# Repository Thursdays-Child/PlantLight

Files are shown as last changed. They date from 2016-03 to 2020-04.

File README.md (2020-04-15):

# PLANT LIGHT 
### Automatic light switch based on light sensor and date/time

**version 3.0**
Replaced transistor with phototransistor to switch the relay. 

**version 2.0**
Upgraded PCB and logic with ATMega328p and Maxim DS3231M RTC. New schematich and new PCB. The temperature compensated clock
now wakes up the micro once per day, with time of day alarm.

**version 1.2**
Added function to set time from an external input, with all the istructions needed: set draft info on RTC clock.
Linked against new ATTiny CORE library, that has changed the RX and TX pin for serial debug.

**version 1.1**

Added TimeZone library to account for DST (summer time). The TimeZone has been added to the DS1307RTC library,
and slightly modified to remove ARDUINO define, not present in my development environment. 
The timezone rules are saved into an EEPROM image (to save program memory on the small ATTiny85): the image is in 
Intel HEX format.

Library reference at https://github.com/JChristensen/Timezone

**version 1.0**

The project is an automatic switch for 2 LED lamps used to illuminate 
some plants in my house. On board there is a real time clock, to keep track of 
the actual date and time even on power loss, and the light sensor is placed 
on a separate breakout board. A relay switches the main power (230 V AC) to 
the LEDs. The micro is an Atmel ATTiny 85V.

The project is compiled for Atmel AVR, with standard AVR GCC toolchain. 
Eclipse was used to create and compile the projects, with the AVR Plugin.

A makefile is available to compile without Eclispe. 

This project consists of a main C++ file and some libraries (C/C++):

* BH1750FVI: control the light sensor (BH1750) to read the lux value and 
  put to sleep/wake up the sensor;
* DS1307: real time clock library, to read the actual date and time.
* TinyWireM: Wire library modified to work on small ATTiny, were the I2C management 
  hardware is not present. The library uses the internal USI hardware to communicate 
  over serial connection, and implement I2C protocol (reference http://playground.arduino.cc/Code/USIi2c).
* TinySerialDebug: library to use serial communication only for debug purpose 
  on the ATTiny. The configuration allows only 3 fixed speeds (baud/s) and the 
  communication is transmission only from the micro (reference https://code.google.com/archive/p/arduino-tiny/).

The sensors library have been modified to work with the same instance of the 
I2C bus control class, and each functionality has been tested with the hardware. 
The documentation folder contains:

* the bill of material;
* datasheet of used components;
* electrical drawings;

Some pictures can be found at https://goo.gl/photos/P42G4u1Tg8iYygQf6

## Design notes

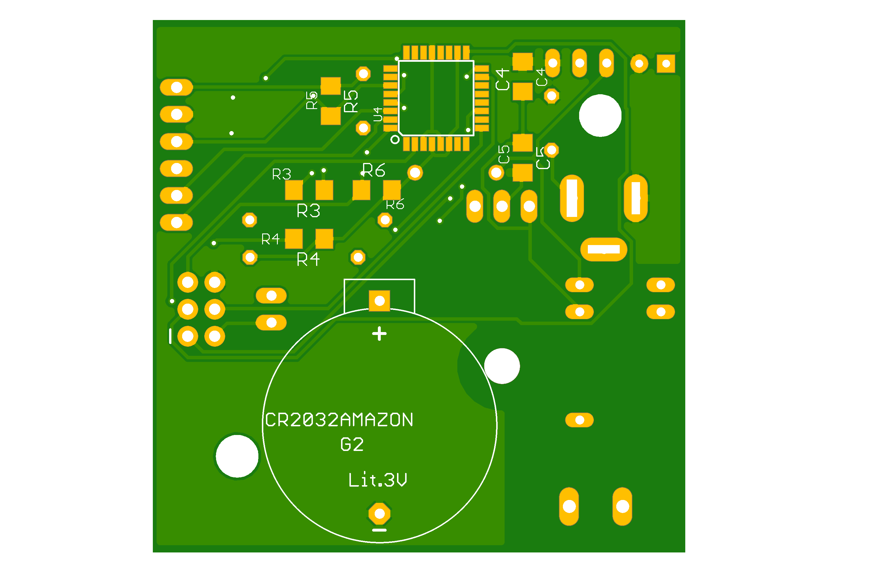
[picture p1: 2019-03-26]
Documentation/Schematics/PlantLight/Main_board_bottom.png

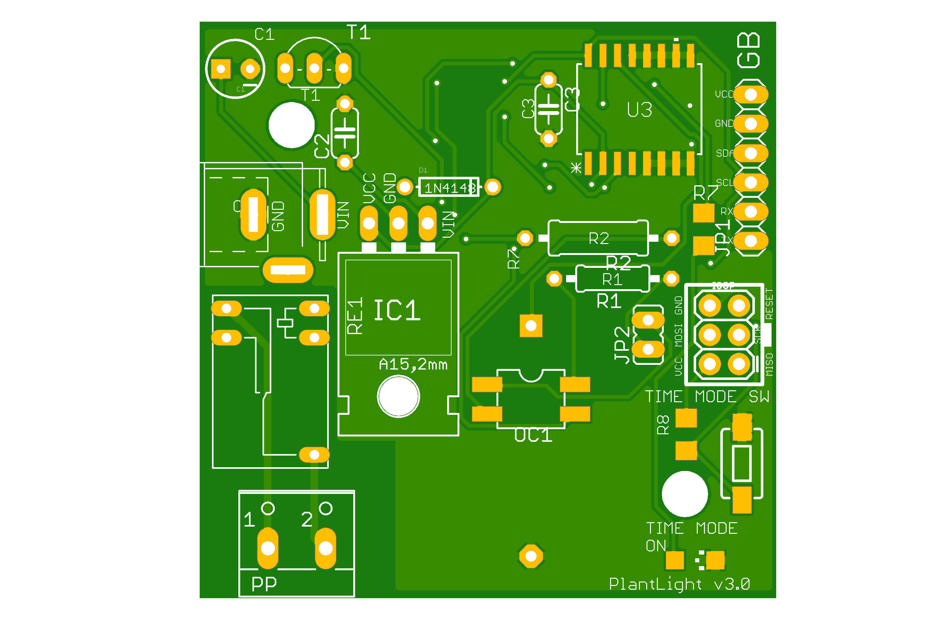
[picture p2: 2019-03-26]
Documentation/Schematics/PlantLight/Main_board_top.png

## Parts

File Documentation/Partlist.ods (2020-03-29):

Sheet: Order
PLANT LIGHT BOARD – TOTAL COST OF ORDER |  |  |  |  |  |  |  | (with tools etc..)
Part | Value | Device | Package | X | Where | Quantity | Price
C1 | 0.33uF | C-US025-024X044 | C025-024X044 |  | EbmStore | 10 | € 0,80
C2 | 100uF | CAP_POLPTH2 | CPOL-RADIAL-10UF-25V | X
C3 | 0.1uF | C-US025-024X044 | C025-024X044 | X
D1 | 1N4148 | DIODE1N4148 | DIODE-1N4148 | X
G1 | CR2032H | CR2032H | CR2032H |  | EbmStore | 1 | € 0,90
IC1 | 5V | 78XXL | 78XXL |  | EbmStore | 2 | € 0,80
IC2 | DS1307 | DS1307 | DIL08 |  | EbmStore | 1 | € 0,90
Q2 | 32768 | CRYTALTC38H | TC38H
JP1 |  | PINHD-1X6 | 1X06 |  | EbmStore | 5 | € 0,90
JP2 |  | PINHD-1X6 | 1X06
PP | 0 | W237-102 | W237-102 | X
Q1 | 2N3904 | TRANSISTOR_NPNTO92 | TO-92 | X
R1 | 1K | R-US_0207/10 | 0207/10 | X
R2 | 10K | R-US_0309/12 | 0309/12 | X
R3 | 10K | R-US_0309/12 | 0309/12 | X
R4 | 4K7 | R-US_0207/10 | 0207/10 |  | EbmStore | 10x2 | € 0,48
R5 | 4K7 | R-US_0207/10 | 0207/10
R6 | 4K7 | R-US_0207/10 | 0207/10
RE1 | R414D | R414D | R414D |  | EbmStore | 2 | € 1,60
U1 | TINY85-20-DIP | ATTINY45TINY85-20-DIP | DIP08 |  | EbmStore | 1 | € 1,80
X1 |  | MPT2 | 2POL254 |  | EbmStore | 2 | € 1,20
 |  | Micro SD reader |  |  | EbmStore | 1 | € 2,80
 |  | ABS box 90x56x23 |  |  | EbmStore | 1 | € 1,20
 |  | 8-DIP socket |  |  | EbmStore | 10 | € 1,00
 |  | RS232 to TTL converter |  |  | EbmStore | 1 | € 3,50
 |  | Flat cable 4 poles 1m |  |  | Ebay | 1 | € 2,70
 |  | BH1750FVI Digital Light Intensity Sensor Module |  |  | Ebay | 1 | € 1,32
 |  | CR2032 coin battery Duracell |  |  | Ebay | 2 | € 2,00
 |  |  |  |  | Paypal tax | Shipment | TOTAL
 |  |  |  |  | € 0,41 | € 8,28 | € 32,59

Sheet: BOM_v1.1
PROJECT BOM
Component | Quantity | Price | Total Cost | Shipment Cost
Electronic
Flat cable 4 poles 1m | 1 | € 2,70 | € 2,70
BH1750FVI Digital Light Intensity Sensor Module | 1 | € 1,32 | € 1,32
CR2032 coin battery Duracell | 2 | € 1,00 | € 2,00 | € 1,78
Capacitor 0.33uF, 100uF, 0.1uF | 3 | € 0,08 | € 0,24 | € 6,50 | EbmStore
Diode 1N4148 | 1 | € 0,00 | € 0,00
Coin battery holder CR2032H | 1 | € 0,90 | € 0,90
5V positive regulator 78XXL | 1 | € 0,80 | € 0,80
RTC DS1307 | 1 | € 0,90 | € 0,90
Pin Header X5 | 2 | € 0,18 | € 0,36
Screw contact W237-102 | 1 | € 0,00 | € 0,00
Transistor 2N3904 | 1 | € 0,00 | € 0,00
Oscillator 32KHz | 1 | € 0,00 | € 0,00
Resistors 1K, 10K, 4K7 | 6 | € 0,02 | € 0,12
Relay 5Vdc – 3A | 1 | € 0,80 | € 0,80
ATTiny85-U | 1 | € 0,00 | € 0,00
Screw contact 2.54mm | 1 | € 0,60 | € 0,60
8-DIP socket | 2 | € 0,10 | € 0,20
BH1750FVI Digital Light Intensity Sensor Module | 1 | € 1,20 | € 1,20
Construction
Flat cable 4 poles 1m | 1 | € 1,30 | € 1,30
ABS box 55x57x28 | 1 | € 1,20 | € 1,20
Bipolar cable | 1 | € 0,50 | € 0,50
220V Socket | 1 | € 2,60 | € 2,60
Sensor holder | 1 | € 1,00 | € 1,00
 |  |  | € 18,74 | € 8,28
 |  |  |  | TOTAL
 |  |  |  | € 27,02

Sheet: BOM_v2.0
X | Part | Value | Device | Package | Library
x | C1 | 100uF | CAP_POLPTH2 | CPOL-RADIAL-10UF-25V | Capacitor Polarized
x | C2 | 0.33uF | C-US050-024X044 | C050-024X044 | CAPACITOR, American symbol
x | C3 | 0.1uF | C-US050-024X044 | C050-024X044 | CAPACITOR, American symbol
x | C4 | 0.1uF | C-EUC1206 | C1206 | CAPACITOR, European symbol
x | C5 | 0.1uF | C-EUC1206 | C1206 | CAPACITOR, European symbol
x | D1 | 1N4148 | DIODE1N4148 | DIODE-1N4148 | Diode
x | G2 | CR2032AMAZON | CR2032AMAZON | CR2032_AMAZON | Battery holder CR2032 from:
x | IC1 | 5V | 78XXL | 78XXL | VOLTAGE REGULATOR
x | ICSP | AVR_SPI_PROG | AVR_SPI_PROG_3X2PTH | 2X3 | AVR ISP 6 Pin
x | JP1 |  | PINHD-1X6 | 1X06 | PIN HEADER
x | PP |  | W237-102 | W237-102 | WAGO SCREW CLAMP
x | R1 | 1K | R-US_0207/10 | 0207/10 | RESISTOR, American symbol
x | R2 | 10K | R-US_0309/12 | 0309/12 | RESISTOR, American symbol
x | R3 | 18K | R-US_R1206 | R1206 | RESISTOR, American symbol
x | R4 | 18K | R-US_R1206 | R1206 | RESISTOR, American symbol
x | R5 | 18K | R-US_R1206 | R1206 | RESISTOR, American symbol
x | R6 | 18K | R-US_R1206 | R1206 | RESISTOR, American symbol
x | R7 | 560 | R-US_R1206 | R1206 | RESISTOR, American symbol
x | R8 | 18K | R-US_R1206 | R1206 | RESISTOR, American symbol
x | RE1 | SRSZ-SL5VDC | SRSZ-SL5VDC | SRSZ-SL | SRSZ-05VDC-SL Relay from EbmStore
x | T1 | 2N3904 | 2N3904-NPN-TO92-EBC | TO92-EBC | NPN Transistror
x | TIME_MODE | YELLOW | LEDCHIPLED_1206 | CHIPLED_1206 | LED
x | TIME_MODE_SW | SPST-SMD | MOMENTARY-SWITCH-SPST-SMD-6.0X3.5MM | TACTILE_SWITCH_SMD_6.0X3.5MM | Momentary Switch (Pushbutton) - SPST
x | U3 | DS3231M+TRL | DS3231M+TRL | 21-0042B_16
x | U4 | ATMEGA8/168/328 | ATMEGA8/168/328 | TQFP32 | MICROCONTROLLER
x | X1 |  | MPT2 | 2POL254 | PHOENIX CONNECTOR

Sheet: BOM_v3.0
X | Part | Value | Device | Package | Description
x | C1 | 100uF | CAP_POLPTH2 | CPOL-RADIAL-10UF-25V | Capacitor Polarized
x | C2 | 0.33uF | C-US050-024X044 | C050-024X044 | CAPACITOR, American symbol
x | C3 | 0.1uF | C-US050-024X044 | C050-024X044 | CAPACITOR, American symbol
x | C4 | 0.1uF | C-EUC1206 | C1206 | CAPACITOR, European symbol
x | C5 | 0.1uF | C-EUC1206 | C1206 | CAPACITOR, European symbol
x | D1 | 1N4148 | DIODE1N4148 | DIODE-1N4148 | Diode
x | G2 | CR2032AMAZON | CR2032AMAZON | CR2032_AMAZON | Battery holder CR2032 from:
x | IC1 | 5V | 78XXL | 78XXL | VOLTAGE REGULATOR
x | ICSP | AVR_SPI_PROG | AVR_SPI_PROG_3X2PTH | 2X3 | AVR ISP 6 Pin
x | J1 |  | JACK-PLUG0 | SPC4077 | DC POWER JACK
x | JP1 |  | PINHD-1X6 | 1X06 | PIN HEADER
x | JP2 |  | JP1E | JP1 | JUMPER
x | OC1 |  | PC817SMD | SMD04 | SHARP OPTO COUPLER
 | PP | 0 | W237-102 | W237-102 | WAGO SCREW CLAMP
x | R1 | 1K | R-US_0207/10 | 0207/10 | RESISTOR, American symbol
x | R2 | 560 | R-US_0309/12 | 0309/12 | RESISTOR, American symbol
x | R3 | 18K | R-US_R1206 | R1206 | RESISTOR, American symbol
x | R4 | 18K | R-US_R1206 | R1206 | RESISTOR, American symbol
x | R5 | 18K | R-US_R1206 | R1206 | RESISTOR, American symbol
x | R6 | 18K | R-US_R1206 | R1206 | RESISTOR, American symbol
x | R7 | 560 | R-US_R1206 | R1206 | RESISTOR, American symbol
x | R8 | 18K | R-US_R1206 | R1206 | RESISTOR, American symbol
x | RE1 | SRSZ-SL5VDC | SRSZ-SL5VDC | SRSZ-SL | SRSZ-05VDC-SL Relay from EbmS
x | T1 |  | 2N5551-NPN-TO92-CBE | TO92-CBE | NPN Transistror
x | TIME_MODE | YELLOW | LEDCHIPLED_1206 | CHIPLED_1206 | LED
x | TIME_MODE_SW | SPST-SMD | MOMENTARY-SWITCH-SPST-SMD-6.0X3.5MM | TACTILE_SWITCH_SMD_6.0X3.5MM | Momentary Switch (Pushbutton)
x | U3 | DS3231M+TRL | DS3231M+TRL | 21-0042B_16 | Real Time Clock
x | U4 | ATMEGA8/168/328 | ATMEGA8/168/328 | TQFP32 | MICROCONTROLLER

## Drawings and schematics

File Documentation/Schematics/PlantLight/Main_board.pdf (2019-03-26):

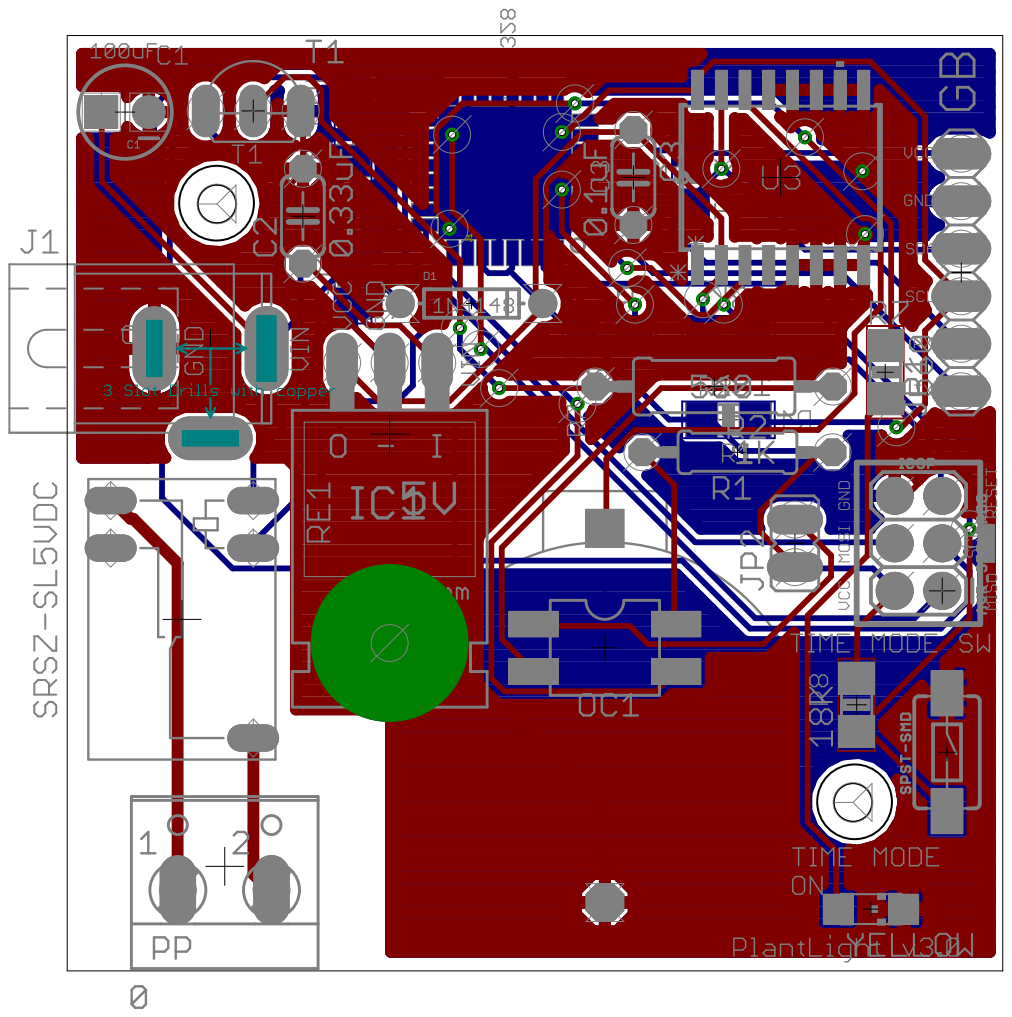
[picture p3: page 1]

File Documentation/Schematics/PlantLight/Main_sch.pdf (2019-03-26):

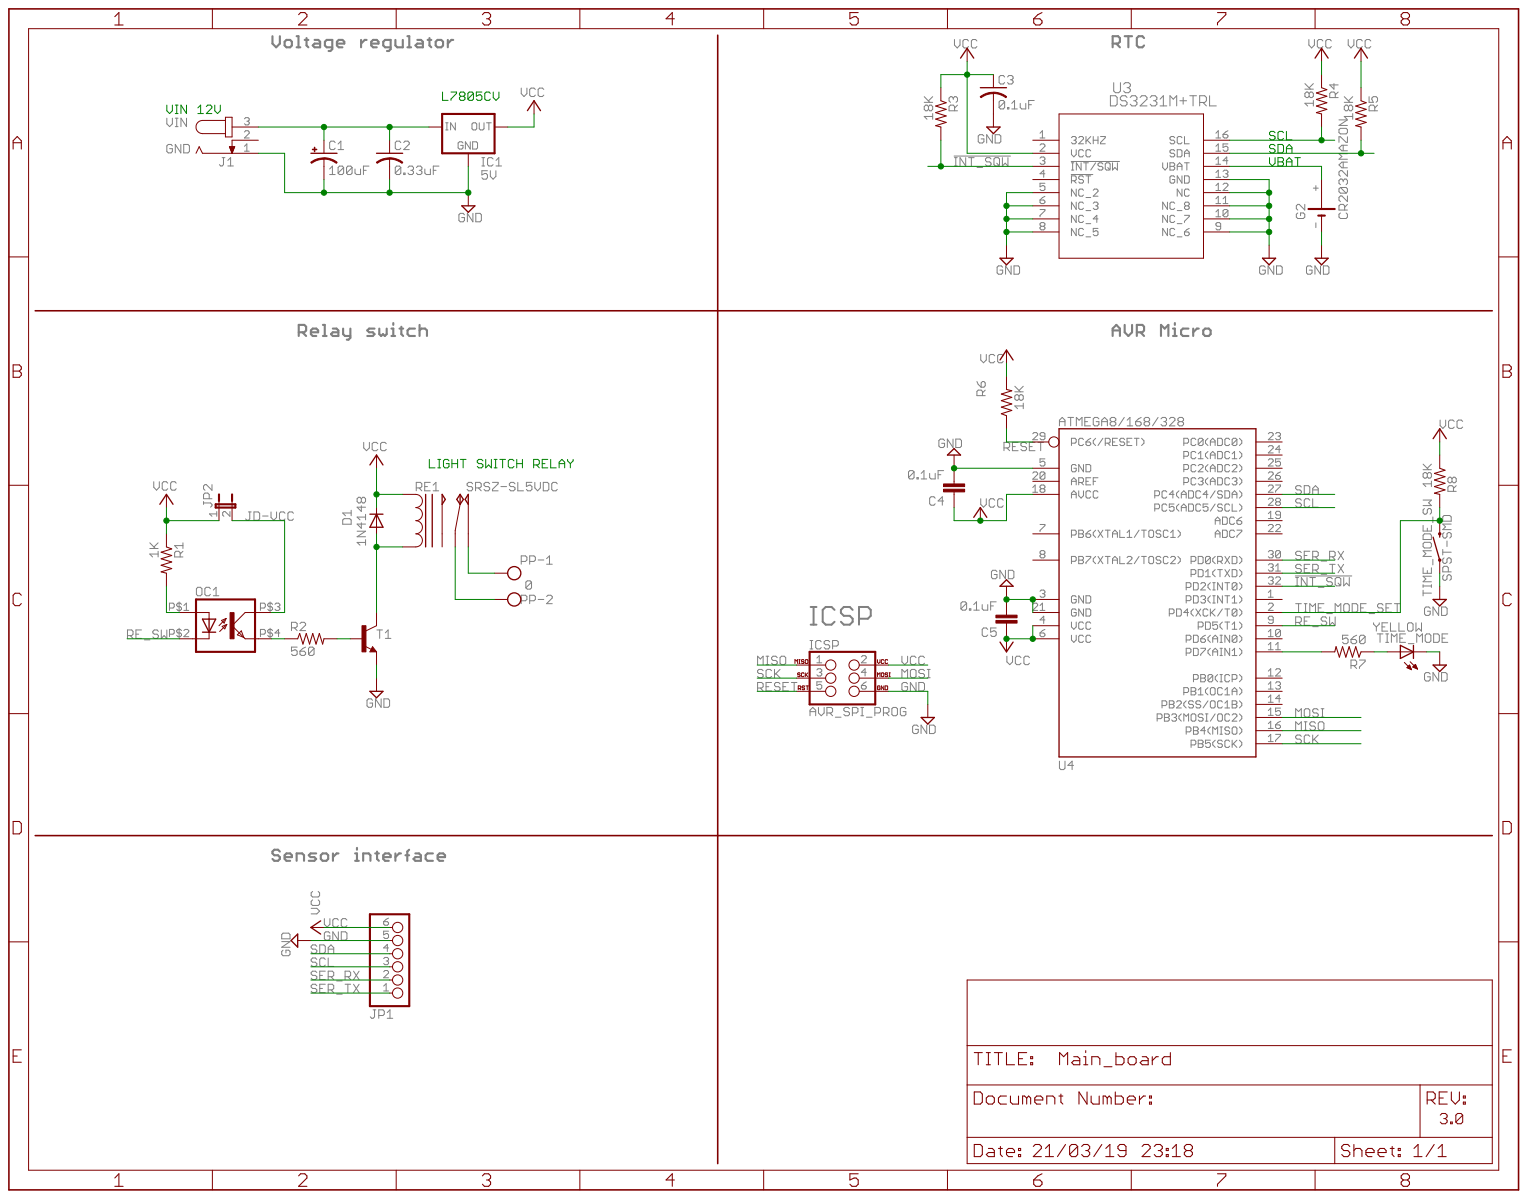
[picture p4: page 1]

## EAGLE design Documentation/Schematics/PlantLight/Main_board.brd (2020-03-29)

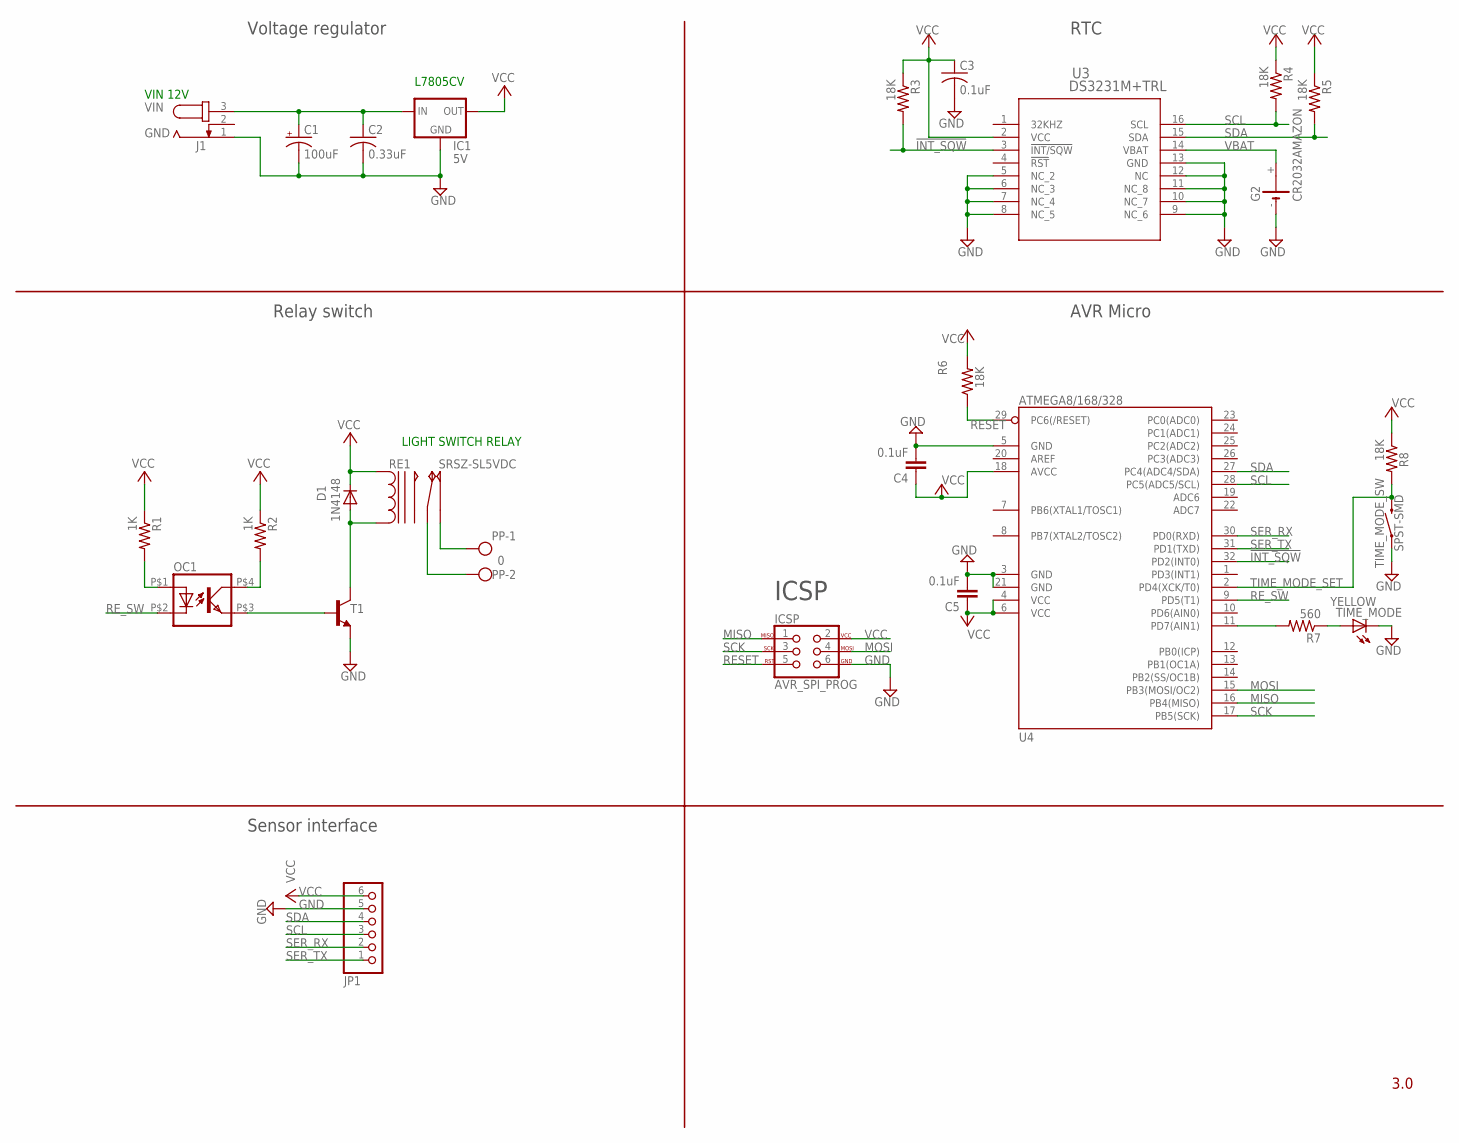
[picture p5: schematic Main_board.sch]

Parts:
C1: 100uF; CPOL-RADIAL-10UF-25V
C2: 0.33uF; C050-024X044
C3: 0.1uF; C050-024X044
C4, C5: 0.1uF; C1206
D1: 1N4148; DIODE-1N4148
G2: CR2032AMAZON; CR2032_AMAZON
IC1: 5V; 78XXL
ICSP: AVR_SPI_PROG; 2X3
J1: JACK-PLUG0; SPC4077
JP1: PINHD-1X6; 1X06
OC1: PC817SMD; SMD04
PP: 0; W237-102
R1, R2: 1K; 0207/10
R3, R4, R5, R6, R8: 18K; R1206
R7: 560; R1206
RE1: SRSZ-SL5VDC; SRSZ-SL
T1: 2N5551-NPN-TO92-CBE; TO92-CBE
TIME_MODE: YELLOW; CHIPLED_1206
TIME_MODE_SW: SPST-SMD; TACTILE_SWITCH_SMD_6.0X3.5MM
U3: DS3231M+TRL; 21-0042B_16
U4: ATMEGA8/168/328; TQFP32

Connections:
!INT_SQW: R3.2, U3.3 (!INT/SQW), U4.32 (PD2(INT0))
GND: C1.2 (-), C2.2, C3.2, C4.2, C5.2, G2.-, IC1.GND, ICSP.6, J1.1, JP1.5, T1.E, TIME_MODE.C, TIME_MODE_SW.1, U3.5 (NC_2), U3.6 (NC_3), U3.7 (NC_4), U3.8 (NC_5), U3.9 (NC_6), U3.10 (NC_7), U3.11 (NC_8), U3.12 (NC), U3.13 (GND), U4.3 (GND), U4.5 (GND), U4.21 (GND)
MISO: ICSP.1, U4.16 (PB4(MISO))
MOSI: ICSP.4, U4.15 (PB3(MOSI/OC2))
unnamed: PP.2, RE1.P$6
unnamed: PP.1, RE1.P$12
unnamed: D1.A, RE1.P$1, T1.C
unnamed: R7.1, TIME_MODE.A
unnamed: R7.2, U4.11 (PD7(AIN1))
OC$1: OC1.P$1 (A), R1.2
OC$3: OC1.P$3 (EMIT), T1.B
OC$4: OC1.P$4 (COL), R2.2
RESET: ICSP.5, R6.1, U4.29 (PC6(/RESET))
RE_SW: OC1.P$2 (C), U4.9 (PD5(T1))
SCK: ICSP.3, U4.17 (PB5(SCK))
SCL: JP1.3, R4.2, U3.16 (SCL), U4.28 (PC5(ADC5/SCL))
SDA: JP1.4, R5.2, U3.15 (SDA), U4.27 (PC4(ADC4/SDA))
SER_RX: JP1.2, U4.30 (PD0(RXD))
SER_TX: JP1.1, U4.31 (PD1(TXD))
TIME_MODE_SET: R8.2, TIME_MODE_SW.2, U4.2 (PD4(XCK/T0))
VBAT: G2.+, U3.14 (VBAT)
VCC: C3.1, C4.1, C5.1, D1.C, IC1.OUT, ICSP.2, JP1.6, R1.1, R2.1, R3.1, R4.1, R5.1, R6.2, R8.1, RE1.P$2, U3.2 (VCC), U4.4 (VCC), U4.6 (VCC), U4.18 (AVCC)
VIN: C1.1 (+), C2.1, IC1.IN, J1.3

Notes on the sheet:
LIGHT SWITCH RELAY
L7805CV
VIN 12V
RTC
Voltage regulator
AVR Micro
ICSP
Sensor interface
Relay switch

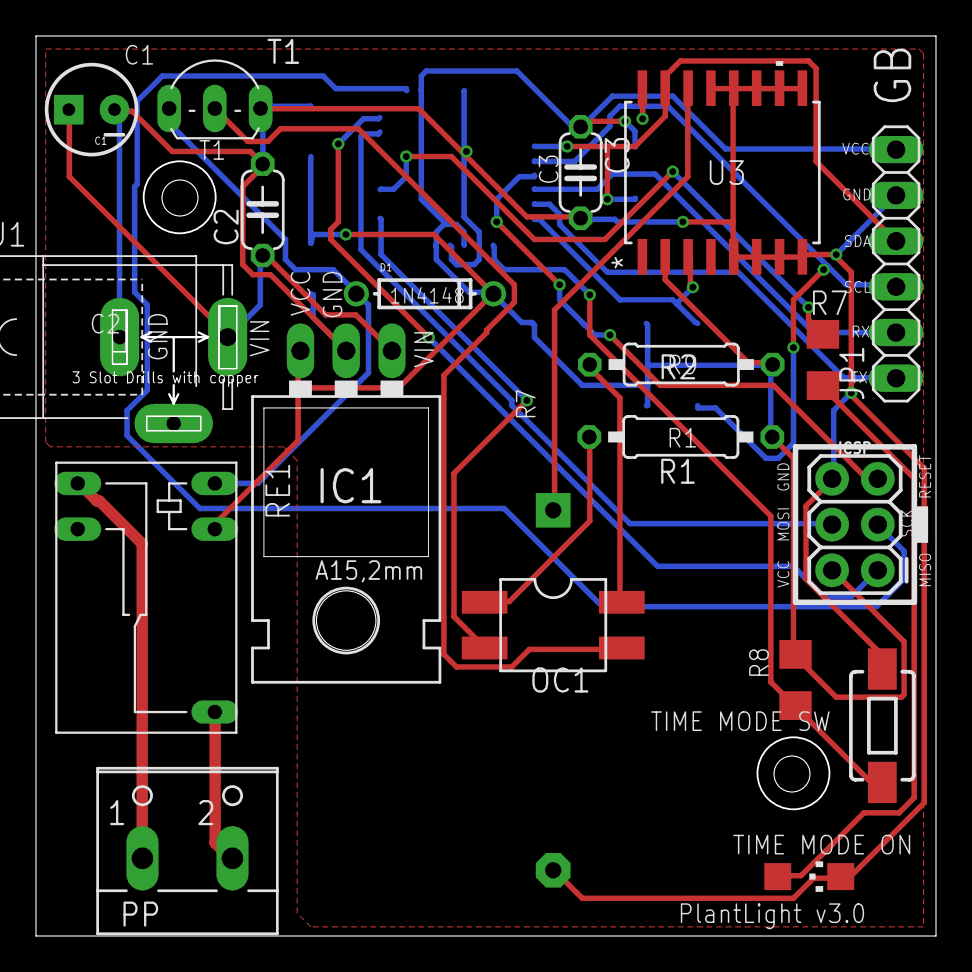
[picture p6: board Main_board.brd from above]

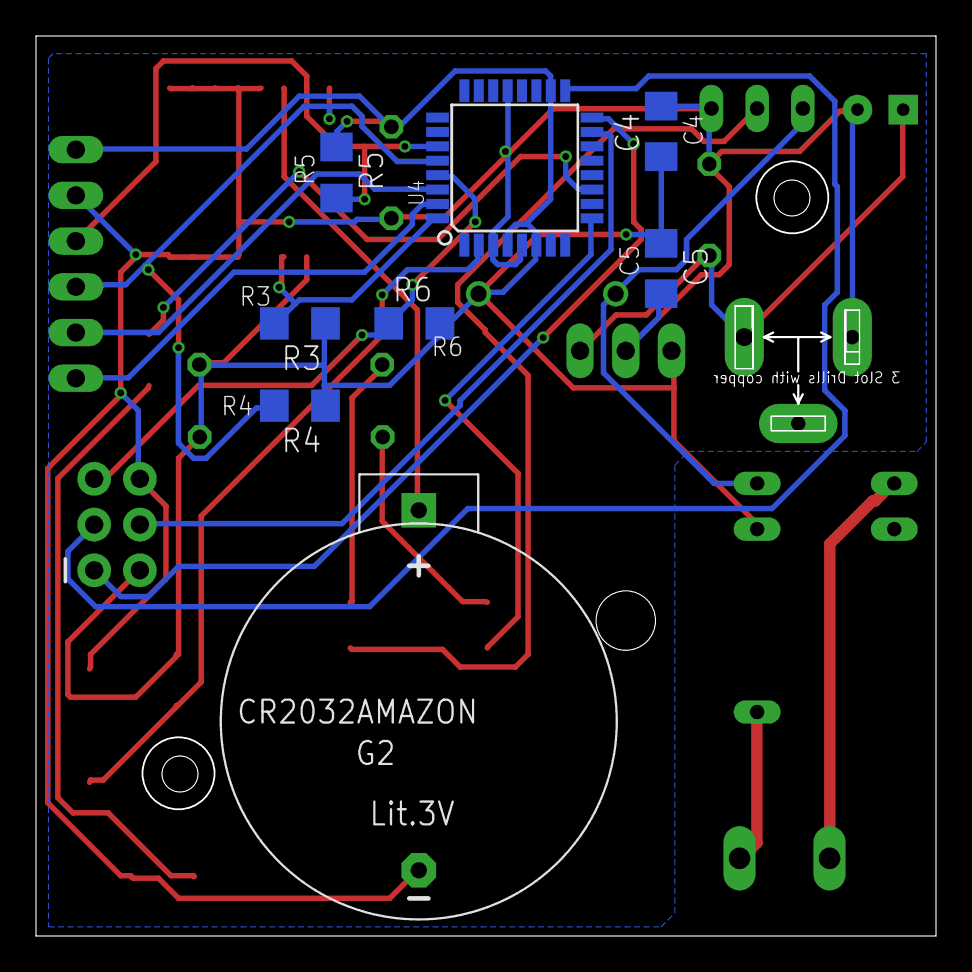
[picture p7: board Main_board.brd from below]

Board: 2 copper layers, 50.0 x 50.0 mm, 27 parts (8 on the bottom side), 23 nets.

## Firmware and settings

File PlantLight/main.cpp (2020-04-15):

/*
 *  This file is part of PlantLight application.
 *
 * Licensed under the Apache License, Version 2.0 (the "License");
 * you may not use this file except in compliance with the License.
 * You may obtain a copy of the License at
 *
 *    http://www.apache.org/licenses/LICENSE-2.0
 *
 * Unless required by applicable law or agreed to in writing, software
 * distributed under the License is distributed on an "AS IS" BASIS,
 * WITHOUT WARRANTIES OR CONDITIONS OF ANY KIND, either express or implied.
 * See the License for the specific language governing permissions and
 * limitations under the License.
 *
 */

/*
 * Built for ATMega328P 1Mhz, using AVR Pololu programmer.
 * VERSION 3.0
 */

#include <avr/sleep.h>
#include <avr/interrupt.h>
#include <avr/pgmspace.h>

#include <Arduino.h>
#include <Timezone.h>
#include <BH1750FVI.h>
#include <DS3232RTC.h>

#include "PowerUtils.h"
#include "TimeUtils.h"

#define SERIAL_BAUD          9600       // Serial baud per second

// Pins
#define RTC_INT_SQW             2       // INT/SQW pin from RTC: external interrupt
#define TIME_MODE_SET           4       // Set time mode input pin: pin change interrupt
#define RELAY_SW_OUT            5       // Relay output pin
#define TIME_MODE_LED           7       // Time mode LED

#define ENABLE_H               16       // Enable hour (default)
#define DISABLE_H              23       // Disable hour (default)
#define ENA_DIS_MIN             0       // Enable and disable minute (default)

#define SET_TIME_MODE_WAIT      1       // Set time mode wait (default)     [s]
#define TIME_MODE_TIMEOUT      60       // Set time mode timeout (default)  [s]

#define POLLING_INT            30       // Polling interval (default)       [s]
#define SAMPLE_COUNT           10       // Light sample count (average measurement)
#define MAX_SAMPLE_COUNT       50       // Max light sample count
#define LUX_TH                 10       // Lux threshold
#define LUX_TH_HIST             5       // Lux threshold (hysteresis compensation)

//#define LIGHT_SEN_EMU                 // Enable light sensor emulation
#define LIGHT_SEN_EMU_MAX      35       // Light sensor emulation maximum value

// ################################# Constants ################################

// ################################# Variables ################################

TwoWire bus;                            // TinyWireM instance (I2C bus)
BH1750FVI BH1750(bus);                  // Light sensor instance
DS3232RTC RTC(bus);                     // RTC clock instance

static float luxSamples[MAX_SAMPLE_COUNT] = {};
static uint8_t readCounter = 0;
static int timeOut = 0;
static boolean relayState = false;
volatile boolean setTimeMode = false;
static struct tm utcTime, localTime;

//CET Time Zone (Rome, Berlin) -> UTC/GMT + 1
const TimeChangeRule CEST = {"CEST", Last, Sun, Mar, 2, 120};   // Central European Summer Time
const TimeChangeRule CET  = {"CET ", Last, Sun, Oct, 3, 60};    // Central European Standard Time
Timezone TZ(CEST, CET);                                         // Constructor to build object from DST Rules
TimeChangeRule *tcr;                                            // Pointer to the time change rule, use to get TZ abbreviations

// Options data
typedef struct {
  int8_t hhE, mmE, hhD, mmD;        // Time of day to enable or disable light
} alarm;                            // Alarm structure

alarm alm;                          // Global alarm instance: UTC format!

// ############################################################################
// Sensor reading functions
// ############################################################################

/*
 * Sample from light sensor.
 *
 * Return: the current mobile average value.
 */
float sample() {
  float tmpLux = 0.0;

  // Shift left values in sample array
  for (int i = 0; i < SAMPLE_COUNT - 1; ++i) {
    luxSamples[i] = luxSamples[i + 1];
    tmpLux += luxSamples[i];
  }

#ifdef LIGHT_SEN_EMU
  luxSamples[SAMPLE_COUNT - 1] = rand() % LIGHT_SEN_EMU_MAX;
#else
  luxSamples[SAMPLE_COUNT - 1] = BH1750.getLightIntensity();
#endif

  tmpLux += luxSamples[SAMPLE_COUNT - 1];

  if (readCounter < SAMPLE_COUNT) {
    readCounter++;
  }

  return tmpLux / readCounter;
}

/*
 * Cleans the mobile average array.
 */
void cleanLuxArray() {
  readCounter = 0;
  for (int i = 0; i < SAMPLE_COUNT; ++i) {
    luxSamples[i] = 0.0;
  }
}

/*
 * Checks the light condition to switch the relay on or off.
 *
 * Return: true to turn on the relay.
 */
boolean checkLightCond(float lux) {
  int low = 0, high = 0;
  for (int i = SAMPLE_COUNT / 2 + 1; i < SAMPLE_COUNT - 1; ++i) {
    if (luxSamples[i] <= LUX_TH) {
      low++;
    } else {
      high++;
    }
  }

  if (readCounter >= SAMPLE_COUNT / 2 + 1) {
    // Turn light on
    if (high <= 2 && lux <= LUX_TH) {
      return true;
    }

    // Turn light off
    if (relayState && lux <= LUX_TH + LUX_TH_HIST) {
      return true;
    } else {
      return false;
    }
  }
  return false;
}

/**
 * Return whether or not the current time "utcTime" is within the [enable:disable]
 * hours in the day.
 *
 * ALL TIMES ARE IN UTC FORMAT!
 */
boolean checkEnable(const struct tm &utcTime, const alarm &alm) {
  int minE = alm.hhE * 60 + alm.mmE;
  int minD = alm.hhD * 60 + alm.mmD;
  int nowM = utcTime.tm_hour * 60 + utcTime.tm_min;

  if (minE == minD) {
    return true;
  } else if (minE < minD) {
    return (minE <= nowM && nowM < minD);
  } else {
    return (minE <= nowM || nowM < minD);
  }
}

#ifdef DEBUG
void printLuxArray() {
  for (int i = 0; i < SAMPLE_COUNT; ++i) {
    printDigits(luxSamples[i]);
    Serial.print(" ");
  }
}
#endif

/**
 * Set the date and time by entering the following on the serial input:
 * year,month,day,hour,minute,second,
 *
 * Where
 *  year can be two or four digits,
 *  month is 1-12,
 *  day is 1-31,
 *  hour is 0-23, and
 *  minute and second are 0-59.
 *
 * Entering the final comma delimiter (after "second") will avoid a
 * one-second timeout and will allow the RTC to be set more accurately.
 *
 * No validity checking is done, invalid values or incomplete syntax
 * in the input will result in an incorrect RTC setting.
 *
 * ALL TIMES ARE IN UTC FORMAT, EXCEPT localTime!
 */
boolean setTimeSerial(struct tm *utcTime, struct tm *localTime) {
  int16_t YYYY;                 // Year in 4 digit format
  int8_t MM, DD, hh, mm, ss;

  // Check for input to set the RTC, minimum length is 12, i.e. yy,m,d,h,m,s
  if (Serial.available() >= 12) {
    int y = Serial.parseInt();
    if (y >= 100 && y < 1000) {
      Serial.println(F("Error: Year must be two digits or four digits!"));
    } else {
      if (y >= 1000) {
        YYYY = y;
      } else {
        // (y < 100)
        YYYY = y + 2000;
      }

      MM = Serial.parseInt();
      DD = Serial.parseInt();
      hh = Serial.parseInt();
      mm = Serial.parseInt();
      ss = Serial.parseInt();

      // Set UTC application time
      // Use this version of makeTime() to ensure correct weekday is set
      makeTime(utcTime, YYYY, MM, DD, hh, mm, ss);
      RTC.write(utcTime);

      // Convert UTC time in local time
      TZ.toLocal(utcTime, localTime, &tcr);

      Serial.println(F("RTC set to: "));
      printTime(utcTime, "UTC");
      printTime(localTime, tcr->abbrev);
      Serial.println();

      // Dump any extraneous input
      while (Serial.available() > 0)
        Serial.read();
    }
    return true;
  }
  return false;
}

/*
 * Calculates the enable and disable hour and sets the RTC alarm ALM2_MATCH_HOURS.
 * Local time must be updated before the call.
 */
void setWakeUpAlarm(struct tm *localTime, alarm *alm) {
  int me = 0, md = 0;

  // Calculates the enable and disable hour with DST offset in minutes
  me = (ENABLE_H  * 60 + ENA_DIS_MIN - TZ.getLocalDSTOffset(localTime) + 1440) % 1440;
  md = (DISABLE_H * 60 + ENA_DIS_MIN - TZ.getLocalDSTOffset(localTime) + 1440) % 1440;
  alm->hhE = me / 60;
  alm->mmE = me % 60;
  alm->hhD = md / 60;
  alm->mmD = md % 60;

  // Set alarm to the RTC clock in UTC format!!
  RTC.setAlarm(ALM2_MATCH_HOURS, alm->mmE, alm->hhE, 0);
  // Clear the alarm flag
  RTC.alarm(ALARM_2);
  // Set the alarm interrupt
  RTC.alarmInterrupt(ALARM_2, true);
}

// ############################################################################
// AVR specific functions
// ############################################################################

/*
 *  PCINT Interrupt Service Routines
 */
ISR(PCINT2_vect) {
  setTimeMode = true;
}

/*
 *  INT0 Interrupt Service Routines
 *
 *  External interrupt on PD2
 */
ISR(INT0_vect) {
  // Don't do anything here but we must include this
  // block of code otherwise the interrupt calls an
  // uninitialized interrupt handler.
}

/*
 * Set various power reduction options
 */
static void powerReduction() {
  // Disable digital input buffer on ADC pins
  DIDR0 = (1 << ADC5D) | (1 << ADC4D) | (1 << ADC3D) | (1 << ADC2D) | (1 << ADC1D) | (1 << ADC0D);

  // Disable digital input buffer on Analog comparator pins
  DIDR1 |= (1 << AIN1D) | (1 << AIN0D);

  // Disable Analog Comparator interrupt
  ACSR &= ~(1 << ACIE);

  // Disable Analog Comparator
  ACSR |= (1 << ACD);

  // Disable unused peripherals to save power
  // Disable ADC (ADC must be disabled before shutdown)
  ADCSRA &= ~(1 << ADEN);

  // Enable power reduction register except:
  // - USART0: for serial communications
  // - TWI module: for I2C communications
  // - TIMER0: for millis()
  PRR = 0xFF & (~(1 << PRUSART0)) & (~(1 << PRTWI)) & (~(1 << PRTIM0));
}

void setup() {
  uint8_t retcode;

  Serial.begin(SERIAL_BAUD);

  // I2C begin() is called BEFORE sensors library "begin" methods:
  // it is called just once for all the sensors.
  bus.begin();

  // Setup pins modes
  pinMode(RELAY_SW_OUT, OUTPUT);
  pinMode(TIME_MODE_LED, OUTPUT);
  pinMode(RTC_INT_SQW, INPUT_PULLUP);
  pinMode(TIME_MODE_SET, INPUT_PULLUP);

  // RTC connection check
  if ((retcode = RTC.checkCon()) != 0) {
    Serial.print(F("RTC error: "));
    Serial.println(retcode);
    delay(500);

    // Exit application code to infinite loop
    exit(retcode);
  }

#ifndef LIGHT_SEN_EMU
  // Light sensor connection check
  if ((retcode = BH1750.checkCon()) != 0) {
    Serial.print(F("BH1750 error: "));
    Serial.println(retcode);
    delay(500);

    // Exit application code to infinite loop
    exit(retcode);
  }

  // Light Sensor initialization
  BH1750.powerOn();
  BH1750.setMode(BH1750_CONTINUOUS_HIGH_RES_MODE_2);
  BH1750.setMtreg(200);                 // Set measurement time register to high value
  delay(100);
  BH1750.sleep();                       // Send light sensor to sleep
#endif

  // Real time clock set: UTC time!
  RTC.read(&utcTime);
  TZ.toLocal(&utcTime, &localTime, &tcr);

#ifdef DEBUG
  Serial.println(F("STARTUP"));
  printTime(&utcTime, "UTC");
  printTime(&localTime, tcr->abbrev);
  Serial.println();
#endif

  // Calculates the enable and disable hour and sets the RTC alarm ALARM_2
  setWakeUpAlarm(&localTime, &alm);

  // Power settings
  powerReduction();

  // Interrupt configuration
  PCMSK2 |= _BV(PCINT20);               // Pin change mask: listen to portD bit 4 (D4) (TIME_MODE_SET)
  PCICR  |= _BV(PCIE2);                 // Enable PCINT interrupt on portD

  EICRA |= _BV(ISC01);                  // Set INT0 to trigger on falling edge (RTC_INT_SQW)
  EIMSK |= _BV(INT0);                   // Turns on INT0
}

void loop() {

  RTC.read(&utcTime);
  TZ.toLocal(&utcTime, &localTime, &tcr);

  if (checkEnable(utcTime, alm)) {
    RTC.setAlarm(ALM1_MATCH_SECONDS, (utcTime.tm_sec + POLLING_INT) % 60, 0, 0, 0);
    // Clear the alarm flag
    RTC.alarm(ALARM_1);
    // Set the alarm interrupt
    RTC.alarmInterrupt(ALARM_1, true);

#ifndef LIGHT_SEN_EMU
    // One time mode: the sensor reads and goes into sleep mode autonomously
    BH1750.wakeUp(BH1750_ONE_TIME_HIGH_RES_MODE_2);

    // Wait for the sensor to be fully awake.
    delay(500);
#endif

    float lux = sample();
    relayState = checkLightCond(lux);

#ifdef DEBUG
    printTime(&localTime, tcr->abbrev, false);
    Serial.print(F(" - "));
    printLuxArray();
    Serial.print(F("= "));
    Serial.print(lux);
    Serial.print(F(" "));
    if (relayState)
      Serial.println(F("ON"));
    else
      Serial.println(F("OFF"));
#endif
  } else {

#ifdef DEBUG
    if (!setTimeMode) {
      printTime(&localTime, tcr->abbrev, false);
      Serial.println(F(" - DISABLED"));
    }
#endif

    // Reset the alarm interrupt
    RTC.alarmInterrupt(ALARM_1, false);

    cleanLuxArray();
    relayState = false;
  }

  digitalWrite(RELAY_SW_OUT, relayState);

  if (setTimeMode) {
    // ############################# SET TIME MODE ############################
    Serial.print(F("\nSET TIME MODE: "));
    Serial.print(TIME_MODE_TIMEOUT - timeOut);
    Serial.println(F(" s left"));
    printTime(&utcTime, "UTC");
    printTime(&localTime, tcr->abbrev);
    Serial.println();

    delay(SET_TIME_MODE_WAIT * 1000L);
    timeOut++;

    if (setTimeSerial(&utcTime, &localTime)) {
      // Calculates the enable and disable hour and sets the RTC alarm ALM2_MATCH_HOURS.
      setWakeUpAlarm(&localTime, &alm);
      setTimeMode = false;

      RTC.alarm(ALARM_1);                 // Necessary to reset the alarm flag on RTC!
    }

    // Timeout
    if (timeOut >= TIME_MODE_TIMEOUT) {
      setTimeMode = false;
    }
    digitalWrite(TIME_MODE_LED, HIGH);

  } else {
    timeOut = 0;
    digitalWrite(TIME_MODE_LED, LOW);

    delay(100);                           // Necessary to "flush" the serial buffer!!!
    systemSleep(SLEEP_MODE_PWR_DOWN);     // Send the unit to sleep

    RTC.alarm(ALARM_1);                   // Necessary to reset the alarm flag on RTC!
    RTC.alarm(ALARM_2);                   // Necessary to reset the alarm flag on RTC!
  }
}

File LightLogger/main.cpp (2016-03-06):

/*
 *  This file is part of PlantLight application.
 *
 * Licensed under the Apache License, Version 2.0 (the "License");
 * you may not use this file except in compliance with the License.
 * You may obtain a copy of the License at
 *
 *    http://www.apache.org/licenses/LICENSE-2.0
 *
 * Unless required by applicable law or agreed to in writing, software
 * distributed under the License is distributed on an "AS IS" BASIS,
 * WITHOUT WARRANTIES OR CONDITIONS OF ANY KIND, either express or implied.
 * See the License for the specific language governing permissions and
 * limitations under the License.
 *
 */

#include <Arduino.h>
#include <math.h>
#include <SoftwareSerial.h>
#include <SD.h>

#define SOFT_SERIAL_IN          6
#define SOFT_SERIAL_OUT         7

SoftwareSerial tinySerial(SOFT_SERIAL_IN, SOFT_SERIAL_OUT);
File logFile;
boolean logOk = false;

int readline(int readch, char *buffer, int len) {
  static int pos = 0;
  int rpos;

  if (readch > 0) {
    switch (readch) {
      case '\n': // Ignore new-lines
        break;
      case '\r': // Return on CR
        rpos = pos;
        pos = 0; // Reset position index ready for next time
        return rpos;
      default:
        if (pos < len - 1) {
          buffer[pos++] = readch;
          buffer[pos] = 0;
        }
        break;
    }
  }
  // No end of line has been found, so return -1.
  return -1;
}

void setup() {
  Serial.begin(115200); // Init serial band rate
  tinySerial.begin(9600);

  Serial.print("Initializing SD card...");
  pinMode(SD_CHIP_SELECT_PIN, OUTPUT);

  if (!SD.begin(SD_CHIP_SELECT_PIN)) {
    Serial.println("Initialization failed!");
    return;
  }
  Serial.println("Initialization done.");

  // open the file. note that only one file can be open at a time,
  // so you have to close this one before opening another.
  logFile = SD.open("lightlog.txt", FILE_WRITE);

  // if the file opened okay, write to it:
  if (logFile)
    logOk = true;
  else {
    // if the file didn't open, print an error:
    Serial.println("Error opening file!");
  }

}

void loop() {
  static char buffer[160];

  if (readline(tinySerial.read(), buffer, 160) > 0) {
    Serial.println(buffer);

    if (logOk) {
      logFile.println(buffer);
      logFile.flush();
    }
  }
}

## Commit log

2015-11-28 readme, library code, datasheets, schematics as first version
    [Main_board.brd, Main_board.sch, Partlist.ods]
2015-11-29 Added light log from SD, modified PCB and generated gerber files
    [LightLog.ods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]
2015-12-31 Added support for mtreg calibration and high resolution mode on the sensor. Added comments in class methods
2015-12-31 Changes for test with complete circuit and manual command
2015-12-31 Changed PCB layout for manufcturing (SeedStudio), added gerber file for PCB factory, added test log with light values in the room
    [LightLog.ods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]
2016-02-06 Added support for new RTC library, with drift info. Tested for 10 days it seems to work. Credit for the library code to https://limchonghan.wordpress.com/driftcorrectedds1307/
    [main.cpp]
2016-02-07 Added automatic mode and sampling function, to be completed. Added manual mode with digital input. Added watchdog interval calculation, sensor and micro sleep cycle, corrected RTC driftinfo, to be te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
    [main.cpp]
2016-02-13 Fixed log file init
    [main.cpp]
2016-02-13 Moved SetTime to loop() to be used once with digital input read (more precise). Enabled printDigits to print zero padding in dates (for log purpose). Version 0.6: first version on final PCB
2016-02-13 Version 0.6: first on final PCB
2016-02-19 Modified now() functions and some constants to save space for ATTiny85 micro. The system time can't be counted on the micro since in the sleep period the internal millis() timer is off! Sleep mode PO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
2016-02-19 Added new average filter on lux sensor read, used modified time read funtions (now()) with driftinfo saved in the Time library
    [main.cpp]
2016-02-20 Removed .dat files, updated partlist table
    [Partlist.ods]
2016-03-06 Added hysteresis compensation algorithm, enabled light every month, added flag and memory for relay state, added debug information on relay state.
2016-03-11 Fixed bug in hour condition check
    [main.cpp]
2016-03-11 Added log files and updated LightLog.ods. Release v0.8
    [LightLog.ods]
2016-03-12 Increased delay to wait the sensor to be fully awake, after problems with Serial.printlns not called in release configuration.
    [main.cpp]
2016-03-13 Test version v0.9 with Serial.println active: - set longer period to check the current time and added enable/disabled state, this requires less reads on the RTC when the light management is disabled.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
    [Statistics.ods]
2016-03-13 Added include <avr/iotnx5.h> to avoid indexing problems in Eclipse! (finally!!). Updated version.
    [main.cpp]
2016-03-20 Updated RTC time correction in seconds/day. Cleaned println from code.
    [main.cpp]
2016-10-30 Update README and schematic (base Eagle version)
2016-10-30 Update schematic version with Eagle 7.7.0
    [Main_board.brd, Main_board.sch]
2018-11-04 Fixed comment for watch dog mode.
    [main.cpp]
2018-11-18 First commit for v2.0: ATMega368P and BLE
    [Main_board.brd, Main_board.sch]
2018-11-18 Fixed prj configuration for ATMega 328 (not P). Rewwrite of some functions. Added RTC comunication and watchdog enable/disable (TESTED). Removed prototypes, removed EEPROM image.
    [main.cpp]
2018-11-20 Updated partlist and readme. Eagle design to be reviewd.
    [Main_board.brd, Main_board.sch, Partlist.ods]
2018-11-24 Connected NC pins of RTC to ground.
    [Main_board.brd, Main_board.sch]
2018-11-29 FIXED RTC ALARM: added RTC.alarm() to reset status flag, and used UTC time for the alarm!!!!!!!!! Removed watchdog. (beta003)
    [main.cpp]
2018-12-02 Added "set time mode", function to read date from serial, moved RTC interrupt to external INT0.
2018-12-09 Updated board and schematic with new connections. Removed reset switch and added switch to set time mode. Updated partlist.
    [Main_board.brd, Main_board.sch, Partlist.ods]
2018-12-09 Added timeout on time set mode, enabled light sensors (first test OK), moved logic in loop(), to be tested.
2018-12-24 Fixed time mode switch (pull up) in schematic, fixed 1K resistance package.
    [Main_board.brd, Main_board.sch, Partlist.ods]
2018-12-26 Updated schematich and board with correct simbol for capacitor C3. Updated pdf and gerber file.
    [Main_board.GBL, Main_board.GBO, Main_board.GBP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]
2018-12-28 Rebuilt CAM files, sent to SeeedStudio.
    [Main_board.sch, Partlist.ods]
2018-12-28 Used correct makeTime() function call to get weekday, added global variables as arguments to various functions, removed debug print
    [main.cpp]
2019-01-02 Added "disable" message and seconds left in set time mode. Added Alarm_1 reset on time set.
    [main.cpp]
2019-01-19 Changed resistor value, checked available components, new BOM sheet. Converted to Eagle 9.2.2
    [Main_board.brd, Main_board.sch, Partlist.ods]
2019-01-29 Completed partlist
    [Partlist.ods]
2019-02-11 First build for real PCB, beta 10. Updated project references,
2019-02-16 Update board to v2.1: moved ICSP connector, battery holder to be done.
    [Main_board.GBL, Main_board.GBO, Main_board.GBP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]
2019-02-21 Updated board and schematic with optocoupler and NPN transistor
    [Main_board.brd, Main_board.sch]
2019-03-10 Added PC817 SMD package, DC jack, rerouted board.
    [Main_board.brd, Main_board.sch]
2019-03-17 Added version number b001, moved text near ICSP connector, converted project to Eagle v9.3.1
    [Main_board.brd]
2019-03-21 Updated schematic and PCB with 560 Ohm res, used NO contact on relè. Updated partlist.
    [Main_board.brd, Main_board.sch, Partlist.ods]
2019-03-26 Completed ground plain and gerber for production
    [Main_board.GBL, Main_board.GBO, Main_board.GBP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]
2020-03-29 Removed project reference and added make target to compile only the main program! main.cpp in test..
    [Main_board.brd, Main_board.sch, Partlist.ods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]
2020-03-29 Fixed EL817 optocoupler layout, added 1K resistor and removed transistor base resistor, to be test.
    [Main_board.brd, Main_board.sch]
2020-03-29 Renamed R9 -> R2
    [Main_board.brd, Main_board.sch]
2020-04-04 Setup test with light sensor emulator..
2020-04-15 Tested with light sensor emulator active.

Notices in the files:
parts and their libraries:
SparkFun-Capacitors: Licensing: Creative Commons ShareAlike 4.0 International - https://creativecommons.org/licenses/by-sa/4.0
